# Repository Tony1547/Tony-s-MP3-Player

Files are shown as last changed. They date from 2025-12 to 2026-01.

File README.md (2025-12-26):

# Tony-s-MP3-Player
A custom MP3 player designed to bypass my school's ban on all cellular devices, which also bans over half the internet. How am I supposed to listen to my TF2 soundtrack? This project is also a good first step before I have to make my robot arm's PCB.

Onshape Link: https://cad.onshape.com/documents/4ae9d4a6ef44a3dbc4a2c6f3/w/3289807ef25710fc241d0646/e/3b21fd57c49c14028b7a0996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 

Google Sheets if needed: https://docs.google.com/spreadsheets/d/1tBs17rBeQA4046zbtyh8lai0--RzHnu4pUclCCczuA0/edit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

This is my first non-tutorial followed PCB! The following are pictures of the MP3 in Onshape and Kicad









|  1 | C2962032  | HYCW19-TF09-205B | HOAUC | SMD | | Micro SD card (TF card) Connector and Ejector Push-Push Surface Mount | yes | 5 | 5 | 5 |  0.3308 |  1.65 | 1.65 |
|---:|---|---|---|---|---|---|-----|----:|----:|----:|---:|---:|---:|
|  2 | C105578 | RC0603FR-071ML | YAGEO | 603 | | 100mW 1MΩ 75V ±100ppm/℃ Thick Film Resistor ±1% 0603 Chip Resistor - Surface Mount RoHS | yes | 100 | 100 | 100 |  0.0012 |  0.12 | 1.77 |
|  3 | C14675 | RC0603FR-07100KL | YAGEO | 603 | | 100mW 100kΩ 75V ±100ppm/℃ Thick Film Resistor ±1% 0603 Chip Resistor - Surface Mount RoHS | yes | 100 | 100 | 100 | 0.001 | 0.1 | 1.87 |
|  4 | C22843 | 0603WAF1501T5E | UNI-ROYAL | 603 | | 1.5kΩ ±1% 100mW 0603 Thick Film Resistor | yes | 100 | 100 | 100 |  0.0011 |  0.11 | 1.98 |
|  5 | C870490 | RT1206BRD071K13L | YAGEO | 1206 | | 250mW 1.13kΩ 200V ±25ppm/℃ Thin Film Resistor ±0.1% 1206 Chip Resistor - Surface Mount RoHS | yes |  10 |  10 |  10 |  0.0693 |  0.69 | 2.67 |
|  6 | C2906979  | FRC0603F1801TS | FOJAN | 603 | | 1.8kΩ ±1% 100mW 0603 Thick Film Resistor | yes | 100 | 100 | 100 | 0.001 | 0.1 | 2.77 |
|  7 | C2907044  | FRC0603F5101TS | FOJAN | 603 | | 5.1kΩ ±1% 100mW 0603 Thick Film Resistor | yes | 100 | 100 | 100 |  0.0009 |  0.09 | 2.86 |
|  8 | C782233 | RN73H1JTTD4642B25 | KOA | 603 | | 100mW 46.4kΩ ±25ppm/℃ Metal Film Resistor ±0.1% 0603 Chip Resistor - Surface Mount RoHS | yes | 1 | 1 | 1 |  0.2313 |  0.23 | 3.09 |
|  9 | C1705 | CL10A475KP8NNNC | Samsung Electro-Mechanics | 603 | | 4.7uF ±10% 10V Ceramic Capacitor X5R 0603 | yes |  50 |  50 |  50 |  0.0051 |  0.26 | 3.35 |
| 10 | C1653 | CL10C220JB8NNNC | Samsung Electro-Mechanics | 603 | | 22pF ±5% 50V Ceramic Capacitor C0G 0603 | yes | 100 | 100 | 100 |  0.0038 |  0.38 | 3.73 |
| 11 | C96346 | RC0805FR-07100KL | YAGEO | 805 | | 125mW 100kΩ 150V ±100ppm/℃ Thick Film Resistor ±1% 0805 Chip Resistor - Surface Mount RoHS  | yes | 100 | 100 | 100 |  0.0022 |  0.22 | 3.95 |
| 12 | C28323 | CL21B105KBFNNNE | Samsung Electro-Mechanics | 805 | | 1uF ±10% 50V Ceramic Capacitor X7R 0805 | yes |  20 |  20 |  20 |  0.0092 |  0.18 | 4.13 |
| 13 | C5189822  | CS2012X7R106M100NRE | SAMWHA | 805 | | 10uF ±20% 10V Ceramic Capacitor X7R 0805 | yes |  50 |  50 |  50 |  0.0074 |  0.37 | 4.5 |
| 14 | C170101 | CL31B225KCHSNNE | Samsung Electro-Mechanics | 1206 | | 2.2uF ±10% 100V Ceramic Capacitor X7R 1206 | yes | 5 | 5 | 5 |  0.0758 |  0.38 | 4.88 |
| 15 | C22548 | RC0603FR-071KL | YAGEO | 603 | | 100mW 1kΩ 75V ±100ppm/℃ Thick Film Resistor ±1% 0603 Chip Resistor - Surface Mount RoHS | yes | 100 | 100 | 100 |  0.0011 |  0.11 | 4.99 |
| 16 | C15850 | CL21A106KAYNNNE | Samsung Electro-Mechanics | 805 | | 10uF ±10% 25V Ceramic Capacitor X5R 0805 | yes |  20 |  20 |  20 |  0.0102 | 0.2 | 5.19 |
| 17 | C98220 | RC0603FR-0710KL | YAGEO | 603 | | 100mW 10kΩ 75V ±100ppm/℃ Thick Film Resistor ±1% 0603 Chip Resistor - Surface Mount RoHS | yes | 100 | 100 | 100 |  0.0011 |  0.11 | 5.3 |
| 18 | C1591 | CL10B104KB8NNNC | Samsung Electro-Mechanics | 603 | | 100nF ±10% 50V Ceramic Capacitor X7R 0603 | yes | 100 | 100 | 100 |  0.0026 |  0.26 | 5.56 |
| 19 | C19171390 | YLED0603R | YONGYUTAI | 603 | | Red LED Indication - Discrete 1.8V~2.4V 0603 | yes | 100 | 100 | 100 |  0.0055 |  0.55 | 6.11 |
| 20 | C157929 | S3B-PH-K-S(LF)(SN) | JST | Through Hole,Right Angle,P=2mm | | Connector Header 3 position 2mm Pitch 2A Right Angle -25℃~+85℃ | yes |  10 |  10 |  10 |  0.0433 |  0.43 | 6.54 |
| 21 | C2765186  | TYPE-C 16PIN 2MD(073) | SHOU HAN | SMD | | USB-C (USB TYPE-C) Receptacle Connector 16 Position Surface Mount, Right Angle | yes |  20 |  20 |  20 | 0.06 | 1.2 | 7.74 |
| 22 | C4991872  | SJ-3523-SMT-TR | CUI | SMD | | 1A 12V | yes | 1 | 1 | 1 |  1.3366 |  1.34 | 9.08 |
| 23 | C19171394 | YLED0603B | YONGYUTAI | 603 | | Blue LED Indication - Discrete 2.6V~3.2V 0603 | yes | 100 | 100 | 100 | 0.004 | 0.4 | 9.48 |
| 24 | C1338432  | STM32F401VEH6 | ST | UFBGA-100 | | ARM Cortex-M4 84MHz 81 UFBGA-100 Microcontrollers RoHS | yes | 1 | 1 | 1 |  7.9079 |  7.91 |  17.39 |
| 25 | C5248081  | HS91L02W2C01 | HS | - | | 0.91 128x32 SSD1306 I2C LCD, OLED, Graphic RoHS | yes | 1 | 1 | 1 |  1.9851 |  1.99 |  19.38 |
| 26 | C69901 | TPA6132A2RTER | TI | WQFN-16-EP(3x3) | | 2-Channel Class AB WQFN-16-EP(3x3) Audio Amplifiers RoHS | yes | 1 | 1 | 1 |  1.2295 |  1.23 |  20.61 |
| 27 | C486306 | VS1063A-L | VLSI | LQFP-48(7x7) | | 48kHz LQFP-48(7x7) Audio Special Purpose RoHS | yes | 1 | 1 | 1 |  9.3147 |  9.31 |  29.92 |
| 28 | C15464 | BQ24075RGTR | TI | QFN-16-EP(3x3) | | 4.35V~6.4V Lithium Battery 1.5A QFN-16-EP(3x3) Battery Chargers ICs RoHS | yes | 1 | 1 | 1 |  0.8901 |  0.89 |  30.81 |
| 29 | C26537 | NCP1117ST33T3G | onsemi | SOT-223 | | Linear Voltage Regulator IC Positive Fixed 1 Output 1A SOT-223 | yes | 5 | 5 | 5 |  0.2344 |  1.17 |  31.98 |
| 30 | C720477 | TS-1088-AR02016 | XUNPU | SMD,4x3mm | | Tactile Switch SPST 160gf 2mm SMD (SMT) Tab 4mm x 3mm Surface Mount | yes |  10 |  10 |  10 |  0.0423 |  0.42 | 32.4 |
| 31 | C7294738  | SD2012M28820001 | huaxindianzi | HC-49S-SMD | | Crystal 12.288MHz ±20ppm 20pF 80Ω HC-49S-SMD | yes | 5 | 5 | 5 | 0.076 |  0.38 |  32.78 |
| 32 | | 3.7V 500mAh Rechargeable Lithium Li-ion Polymer Battery | | | | Battery | | 1 | 1 | 1 | $3.99 | $3.99 | $36.77 |
| 33 | | PCB | JLCPCB | | | Custom Printed Circuit Board | | 1 | 1 | 1 | 0.4 |  5.12 | $41.89 |
| 34 | | 3D Prints | | | | Case | | 1 | 1 | 1 | Depends | | |

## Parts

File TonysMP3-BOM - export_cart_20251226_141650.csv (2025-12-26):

Index | LCSC# | MPN | Manufacturer | Package | Customer # | Description | RoHS | Quantity | MOQ | Multiple | Unit Price($) | Extended Price($) | Running Total($) | Product Link
1 | C2962032 | HYCW19-TF09-205B | HOAUC | SMD |  | Micro SD card (TF card) Connector and Ejector Push-Push Surface Mount | yes | 5 | 5 | 5 | 0.3308 | 1.65 | 1.65 | https://www.lcsc.com/product-detail/C2962032.html
2 | C105578 | RC0603FR-071ML | YAGEO | 603 |  | 100mW 1MΩ 75V ±100ppm/℃ Thick Film Resistor ±1% 0603 Chip Resistor - Surface Mount RoHS | yes | 100 | 100 | 100 | 0.0012 | 0.12 | 1.77 | https://www.lcsc.com/product-detail/C105578.html
3 | C14675 | RC0603FR-07100KL | YAGEO | 603 |  | 100mW 100kΩ 75V ±100ppm/℃ Thick Film Resistor ±1% 0603 Chip Resistor - Surface Mount RoHS | yes | 100 | 100 | 100 | 0.001 | 0.1 | 1.87 | https://www.lcsc.com/product-detail/C14675.html
4 | C22843 | 0603WAF1501T5E | UNI-ROYAL | 603 |  | 1.5kΩ ±1% 100mW 0603 Thick Film Resistor | yes | 100 | 100 | 100 | 0.0011 | 0.11 | 1.98 | https://www.lcsc.com/product-detail/C22843.html
5 | C870490 | RT1206BRD071K13L | YAGEO | 1206 |  | 250mW 1.13kΩ 200V ±25ppm/℃ Thin Film Resistor ±0.1% 1206 Chip Resistor - Surface Mount RoHS | yes | 10 | 10 | 10 | 0.0693 | 0.69 | 2.67 | https://www.lcsc.com/product-detail/C870490.html
6 | C2906979 | FRC0603F1801TS | FOJAN | 603 |  | 1.8kΩ ±1% 100mW 0603 Thick Film Resistor | yes | 100 | 100 | 100 | 0.001 | 0.1 | 2.77 | https://www.lcsc.com/product-detail/C2906979.html
7 | C2907044 | FRC0603F5101TS | FOJAN | 603 |  | 5.1kΩ ±1% 100mW 0603 Thick Film Resistor | yes | 100 | 100 | 100 | 0.0009 | 0.09 | 2.86 | https://www.lcsc.com/product-detail/C2907044.html
8 | C782233 | RN73H1JTTD4642B25 | KOA | 603 |  | 100mW 46.4kΩ ±25ppm/℃ Metal Film Resistor ±0.1% 0603 Chip Resistor - Surface Mount RoHS | yes | 1 | 1 | 1 | 0.2313 | 0.23 | 3.09 | https://www.lcsc.com/product-detail/C782233.html
9 | C1705 | CL10A475KP8NNNC | Samsung Electro-Mechanics | 603 |  | 4.7uF ±10% 10V Ceramic Capacitor X5R 0603 | yes | 50 | 50 | 50 | 0.0051 | 0.26 | 3.35 | https://www.lcsc.com/product-detail/C1705.html
10 | C1653 | CL10C220JB8NNNC | Samsung Electro-Mechanics | 603 |  | 22pF ±5% 50V Ceramic Capacitor C0G 0603 | yes | 100 | 100 | 100 | 0.0038 | 0.38 | 3.73 | https://www.lcsc.com/product-detail/C1653.html
11 | C96346 | RC0805FR-07100KL | YAGEO | 805 |  | 125mW 100kΩ 150V ±100ppm/℃ Thick Film Resistor ±1% 0805 Chip Resistor - Surface Mount RoHS | yes | 100 | 100 | 100 | 0.0022 | 0.22 | 3.95 | https://www.lcsc.com/product-detail/C96346.html
12 | C28323 | CL21B105KBFNNNE | Samsung Electro-Mechanics | 805 |  | 1uF ±10% 50V Ceramic Capacitor X7R 0805 | yes | 20 | 20 | 20 | 0.0092 | 0.18 | 4.13 | https://www.lcsc.com/product-detail/C28323.html
13 | C5189822 | CS2012X7R106M100NRE | SAMWHA | 805 |  | 10uF ±20% 10V Ceramic Capacitor X7R 0805 | yes | 50 | 50 | 50 | 0.0074 | 0.37 | 4.5 | https://www.lcsc.com/product-detail/C5189822.html
14 | C170101 | CL31B225KCHSNNE | Samsung Electro-Mechanics | 1206 |  | 2.2uF ±10% 100V Ceramic Capacitor X7R 1206 | yes | 5 | 5 | 5 | 0.0758 | 0.38 | 4.88 | https://www.lcsc.com/product-detail/C170101.html
15 | C22548 | RC0603FR-071KL | YAGEO | 603 |  | 100mW 1kΩ 75V ±100ppm/℃ Thick Film Resistor ±1% 0603 Chip Resistor - Surface Mount RoHS | yes | 100 | 100 | 100 | 0.0011 | 0.11 | 4.99 | https://www.lcsc.com/product-detail/C22548.html
16 | C15850 | CL21A106KAYNNNE | Samsung Electro-Mechanics | 805 |  | 10uF ±10% 25V Ceramic Capacitor X5R 0805 | yes | 20 | 20 | 20 | 0.0102 | 0.2 | 5.19 | https://www.lcsc.com/product-detail/C15850.html
17 | C98220 | RC0603FR-0710KL | YAGEO | 603 |  | 100mW 10kΩ 75V ±100ppm/℃ Thick Film Resistor ±1% 0603 Chip Resistor - Surface Mount RoHS | yes | 100 | 100 | 100 | 0.0011 | 0.11 | 5.3 | https://www.lcsc.com/product-detail/C98220.html
18 | C1591 | CL10B104KB8NNNC | Samsung Electro-Mechanics | 603 |  | 100nF ±10% 50V Ceramic Capacitor X7R 0603 | yes | 100 | 100 | 100 | 0.0026 | 0.26 | 5.56 | https://www.lcsc.com/product-detail/C1591.html
19 | C19171390 | YLED0603R | YONGYUTAI | 603 |  | Red LED Indication - Discrete 1.8V~2.4V 0603 | yes | 100 | 100 | 100 | 0.0055 | 0.55 | 6.11 | https://www.lcsc.com/product-detail/C19171390.html
20 | C157929 | S3B-PH-K-S(LF)(SN) | JST | Through Hole,Right Angle,P=2mm |  | Connector Header 3 position 2mm Pitch 2A Right Angle -25℃~+85℃ | yes | 10 | 10 | 10 | 0.0433 | 0.43 | 6.54 | https://www.lcsc.com/product-detail/C157929.html
21 | C2765186 | TYPE-C 16PIN 2MD(073) | SHOU HAN | SMD |  | USB-C (USB TYPE-C) Receptacle Connector 16 Position Surface Mount, Right Angle | yes | 20 | 20 | 20 | 0.06 | 1.2 | 7.74 | https://www.lcsc.com/product-detail/C2765186.html
22 | C4991872 | SJ-3523-SMT-TR | CUI | SMD |  | 1A 12V | yes | 1 | 1 | 1 | 1.3366 | 1.34 | 9.08 | https://www.lcsc.com/product-detail/C4991872.html
23 | C19171394 | YLED0603B | YONGYUTAI | 603 |  | Blue LED Indication - Discrete 2.6V~3.2V 0603 | yes | 100 | 100 | 100 | 0.004 | 0.4 | 9.48 | https://www.lcsc.com/product-detail/C19171394.html
24 | C1338432 | STM32F401VEH6 | ST | UFBGA-100 |  | ARM Cortex-M4 84MHz 81 UFBGA-100 Microcontrollers RoHS | yes | 1 | 1 | 1 | 7.9079 | 7.91 | 17.39 | https://www.lcsc.com/product-detail/C1338432.html
25 | C5248081 | HS91L02W2C01 | HS | - |  | 0.91 128x32 SSD1306 I2C LCD, OLED, Graphic RoHS | yes | 1 | 1 | 1 | 1.9851 | 1.99 | 19.38 | https://www.lcsc.com/product-detail/C5248081.html
26 | C69901 | TPA6132A2RTER | TI | WQFN-16-EP(3x3) |  | 2-Channel Class AB WQFN-16-EP(3x3) Audio Amplifiers RoHS | yes | 1 | 1 | 1 | 1.2295 | 1.23 | 20.61 | https://www.lcsc.com/product-detail/C69901.html
27 | C486306 | VS1063A-L | VLSI | LQFP-48(7x7) |  | 48kHz LQFP-48(7x7) Audio Special Purpose RoHS | yes | 1 | 1 | 1 | 9.3147 | 9.31 | 29.92 | https://www.lcsc.com/product-detail/C486306.html
28 | C15464 | BQ24075RGTR | TI | QFN-16-EP(3x3) |  | 4.35V~6.4V Lithium Battery 1.5A QFN-16-EP(3x3) Battery Chargers ICs RoHS | yes | 1 | 1 | 1 | 0.8901 | 0.89 | 30.81 | https://www.lcsc.com/product-detail/C15464.html
29 | C26537 | NCP1117ST33T3G | onsemi | SOT-223 |  | Linear Voltage Regulator IC Positive Fixed 1 Output 1A SOT-223 | yes | 5 | 5 | 5 | 0.2344 | 1.17 | 31.98 | https://www.lcsc.com/product-detail/C26537.html
30 | C720477 | TS-1088-AR02016 | XUNPU | SMD,4x3mm |  | Tactile Switch SPST 160gf 2mm SMD (SMT) Tab 4mm x 3mm Surface Mount | yes | 10 | 10 | 10 | 0.0423 | 0.42 | 32.4 | https://www.lcsc.com/product-detail/C720477.html
31 | C7294738 | SD2012M28820001 | huaxindianzi | HC-49S-SMD |  | Crystal 12.288MHz ±20ppm 20pF 80Ω HC-49S-SMD | yes | 5 | 5 | 5 | 0.076 | 0.38 | 32.78 | https://www.lcsc.com/product-detail/C7294738.html
32 |  | 3.7V 500mAh Rechargeable Lithium Li-ion Polymer Battery |  |  |  | Battery |  | 1 | 1 | 1 | $3.99 | $3.99 | $36.77 | https://www.aliexpress.us/w/wholesale-3.7v-li%2525252dion-500mah-Battery.html
33 |  | PCB | JLCPCB |  |  | Custom Printed Circuit Board |  | 1 | 1 | 1 | 0.4 | 5.12 | $41.89 | https://github.com/Tony1547/Tony-s-MP3-Player
34 |  | 3D Prints |  |  |  | Case |  | 1 | 1 | 1 | Depends |  |  | https://cad.onshape.com/documents/4ae9d4a6ef44a3dbc4a2c6f3/w/3289807ef25710fc241d0646/e/3b21fd57c49c14028b7a0996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

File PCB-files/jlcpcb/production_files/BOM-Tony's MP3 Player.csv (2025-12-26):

Comment | Designator | Footprint | LCSC | Quantity
Back | S4 | SW_TS-1088-AR02016 | C720477 | 1
Down | S7 | SW_TS-1088-AR02016 | C720477 | 1
HYCW19-TF09-205B | U4 | MICRO-SD-SMD_HYCW19-TF09-205B | C2962032 | 1
Left | S8 | SW_TS-1088-AR02016 | C720477 | 1
Power On/Off | S9 | SW_TS-1088-AR02016 | C720477 | 1
Right | S2 | SW_TS-1088-AR02016 | C720477 | 1
Select | S5 | SW_TS-1088-AR02016 | C720477 | 1
Up | S6 | SW_TS-1088-AR02016 | C720477 | 1
Vol+ | S1 | SW_TS-1088-AR02016 | C720477 | 1
Vol- | S3 | SW_TS-1088-AR02016 | C720477 | 1
10uf | C31 | C_0201_0603Metric_Pad0.64x0.40mm_HandSolder |  | 1
R | R10k1 | R_0201_0603Metric_Pad0.64x0.40mm_HandSolder |  | 1
4.7uf | C29 | C_0201_0603Metric_Pad0.64x0.40mm_HandSolder |  | 1
2.2uf | C33 | C_0201_0603Metric_Pad0.64x0.40mm_HandSolder |  | 1
1uf | C30 | C_0201_0603Metric_Pad0.64x0.40mm_HandSolder |  | 1
5.1k | R4 | R_0201_0603Metric_Pad0.64x0.40mm_HandSolder |  | 1
1k | R15 | R_0201_0603Metric_Pad0.64x0.40mm_HandSolder |  | 1
10k | R2 | R_0201_0603Metric_Pad0.64x0.40mm_HandSolder |  | 1
5.1k | R6 | R_0201_0603Metric_Pad0.64x0.40mm_HandSolder |  | 1
1.8k | R3 | R_0201_0603Metric_Pad0.64x0.40mm_HandSolder |  | 1
10k | R21 | R_0201_0603Metric_Pad0.64x0.40mm_HandSolder |  | 1
1uf | C20 | C_0201_0603Metric_Pad0.64x0.40mm_HandSolder |  | 1
Crystal | Y1 | Crystal_SMD_MicroCrystal_CC1V-T1A-2Pin_8.0x3.7mm_HandSoldering |  | 1
NCP1117-3.3_SOT223 | U6 | SOT-223-3_TabPin2 |  | 1
BQ24075RGT | U5 | VQFN-16-1EP_3x3mm_P0.5mm_EP1.6x1.6mm |  | 1
VLSI VS1063A-L | U3 | LQFP-48_L7.0-W7.0-P0.50-LS9.0-BL |  | 1
TI TPA6132A2RTER | U2 | WQFN-16_L3.0-W3.0-P0.50-TL-EP1.6 |  | 1
STM32F401VEH6 | U1 | UFBGA-100_L7.0-W7.0-P0.50-TL_ST_STM32 |  | 1
1.8k | R50 | R_0201_0603Metric_Pad0.64x0.40mm_HandSolder |  | 1
10k | R20 | R_0201_0603Metric_Pad0.64x0.40mm_HandSolder |  | 1
10k | R19 | R_0201_0603Metric_Pad0.64x0.40mm_HandSolder |  | 1
1k | R18 | R_0201_0603Metric_Pad0.64x0.40mm_HandSolder |  | 1
1k | R17 | R_0201_0603Metric_Pad0.64x0.40mm_HandSolder |  | 1
1k | R16 | R_0201_0603Metric_Pad0.64x0.40mm_HandSolder |  | 1
1k | R14 | R_0201_0603Metric_Pad0.64x0.40mm_HandSolder |  | 1
1k | R13 | R_0201_0603Metric_Pad0.64x0.40mm_HandSolder |  | 1
1k | R12 | R_0201_0603Metric_Pad0.64x0.40mm_HandSolder |  | 1
1k | R11 | R_0201_0603Metric_Pad0.64x0.40mm_HandSolder |  | 1
100k | R10 | R_0201_0603Metric_Pad0.64x0.40mm_HandSolder |  | 1
100k | R9 | R_0201_0603Metric_Pad0.64x0.40mm_HandSolder |  | 1
100k | R8 | R_0201_0603Metric_Pad0.64x0.40mm_HandSolder |  | 1
10k | R7 | R_0201_0603Metric_Pad0.64x0.40mm_HandSolder |  | 1
46.4k | R5 | R_0201_0603Metric_Pad0.64x0.40mm_HandSolder |  | 1
10k | R1 | R_0201_0603Metric_Pad0.64x0.40mm_HandSolder |  | 1
HS91L02W2C01 | OLED1 | OLED-TH_L38.0-W12.0_HS91L02W2C01 |  | 1
Conn_01x03 | J4 | JST_PH_S3B-PH-K_1x03_P2.00mm_Horizontal |  | 1
AudioJack | J2 | AUDIO-SMD_SJ-3524-SMT-TR-BE |  | 1
USB_C_Receptacle_USB2.0_16P | J1 | USB_C_Receptacle_Palconn_UTC16-G |  | 1
RED | D1 | LED_0201_0603Metric_Pad0.64x0.40mm_HandSolder |  | 1
100nf | C36 | C_0201_0603Metric_Pad0.64x0.40mm_HandSolder |  | 1
100n | C35 | C_0201_0603Metric_Pad0.64x0.40mm_HandSolder |  | 1
2.2uf | C34 | C_0201_0603Metric_Pad0.64x0.40mm_HandSolder |  | 1
10uf | C32 | C_0201_0603Metric_Pad0.64x0.40mm_HandSolder |  | 1
4.7uf | C28 | C_0201_0603Metric_Pad0.64x0.40mm_HandSolder |  | 1
1uf | C27 | C_0201_0603Metric_Pad0.64x0.40mm_HandSolder |  | 1
100nf | C23 | C_0201_0603Metric_Pad0.64x0.40mm_HandSolder |  | 1
22pf | C22 | C_0201_0603Metric_Pad0.64x0.40mm_HandSolder |  | 1
22pf | C21 | C_0201_0603Metric_Pad0.64x0.40mm_HandSolder |  | 1
100nf | C19 | C_0201_0603Metric_Pad0.64x0.40mm_HandSolder |  | 1
100nf | C18 | C_0201_0603Metric_Pad0.64x0.40mm_HandSolder |  | 1
100nf | C17 | C_0201_0603Metric_Pad0.64x0.40mm_HandSolder |  | 1
10uf | C16 | CP_Axial_L10.0mm_D4.5mm_P15.00mm_Horizontal |  | 1
10uf | C15 | CP_Axial_L10.0mm_D4.5mm_P15.00mm_Horizontal |  | 1
100nf | C14 | C_0201_0603Metric_Pad0.64x0.40mm_HandSolder |  | 1
100nf | C13 | C_0201_0603Metric_Pad0.64x0.40mm_HandSolder |  | 1
100nf | C12 | C_0201_0603Metric_Pad0.64x0.40mm_HandSolder |  | 1
1uf | C11 | C_0201_0603Metric_Pad0.64x0.40mm_HandSolder |  | 1
2.2uf | C10 | C_0201_0603Metric_Pad0.64x0.40mm_HandSolder |  | 1
1uf | C9 | C_0201_0603Metric_Pad0.64x0.40mm_HandSolder |  | 1
100nf | C8 | C_0201_0603Metric_Pad0.64x0.40mm_HandSolder |  | 1
10uf | C7 | CP_Axial_L10.0mm_D4.5mm_P15.00mm_Horizontal |  | 1
1uf | C6 | C_0201_0603Metric_Pad0.64x0.40mm_HandSolder |  | 1
1uf | C5 | C_0201_0603Metric_Pad0.64x0.40mm_HandSolder |  | 1
1uf | C4 | C_0201_0603Metric_Pad0.64x0.40mm_HandSolder |  | 1
1uf | C3 | C_0201_0603Metric_Pad0.64x0.40mm_HandSolder |  | 1
1uf | C2 | C_0201_0603Metric_Pad0.64x0.40mm_HandSolder |  | 1
1uf | C1 | C_0201_0603Metric_Pad0.64x0.40mm_HandSolder |  | 1
LED | BLUE1 | LED_0201_0603Metric_Pad0.64x0.40mm_HandSolder |  | 1
R | 100K2 | R_0201_0603Metric_Pad0.64x0.40mm_HandSolder |  | 1
R | 100k1 | R_0201_0603Metric_Pad0.64x0.40mm_HandSolder |  | 1
R | 1M1 | R_0201_0603Metric_Pad0.64x0.40mm_HandSolder |  | 1
R | 1.18k1 | R_0201_0603Metric_Pad0.64x0.40mm_HandSolder |  | 1
R | 1.13k1 | R_0201_0603Metric_Pad0.64x0.40mm_HandSolder |  | 1
R | 1.5k2 | R_0201_0603Metric_Pad0.64x0.40mm_HandSolder |  | 1
R | 1.5k1 | R_0201_0603Metric_Pad0.64x0.40mm_HandSolder |  | 1

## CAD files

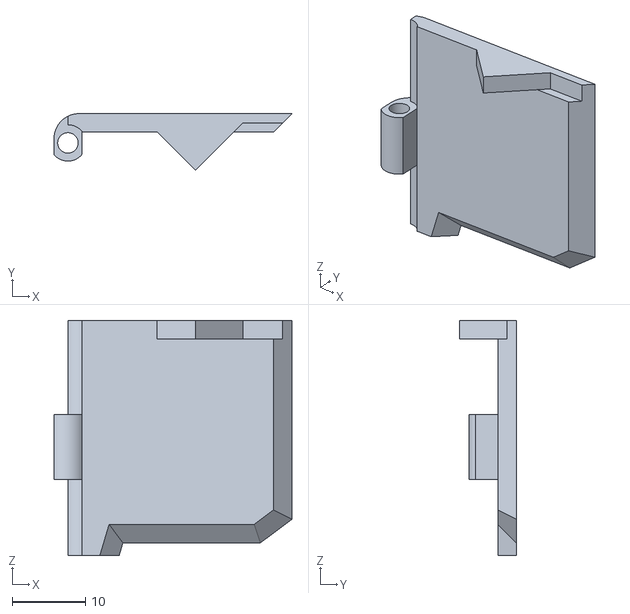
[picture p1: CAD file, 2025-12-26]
Case/Case - Part 3.stl
32.5 x 7.77 x 32.2

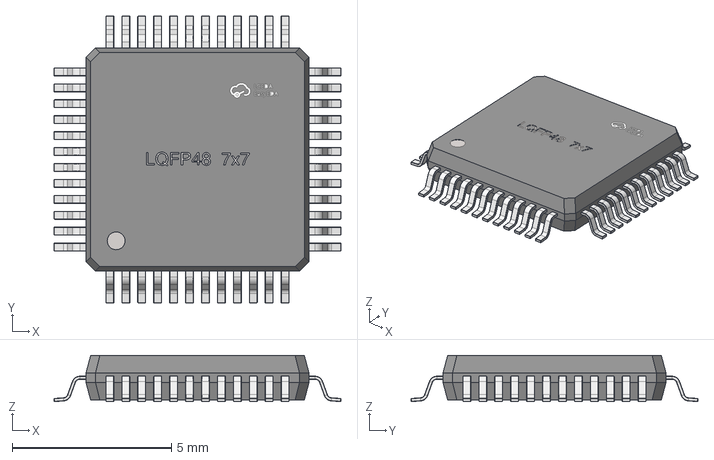
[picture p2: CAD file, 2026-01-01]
PCB-files/EASYEDA_MODELS/LQFP-48_L7.0-W7.0-H1.4-LS9.0-P0.50.step
9.01 x 9.01 x 1.45 mm

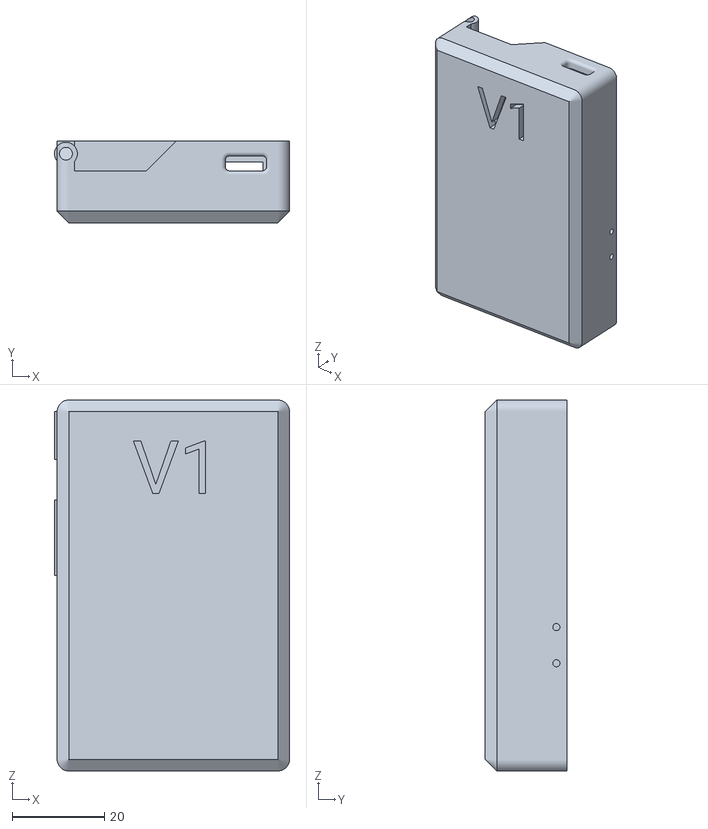
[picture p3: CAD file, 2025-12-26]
Case/Case - Part 1.stl
51.1 x 17.8 x 80.6

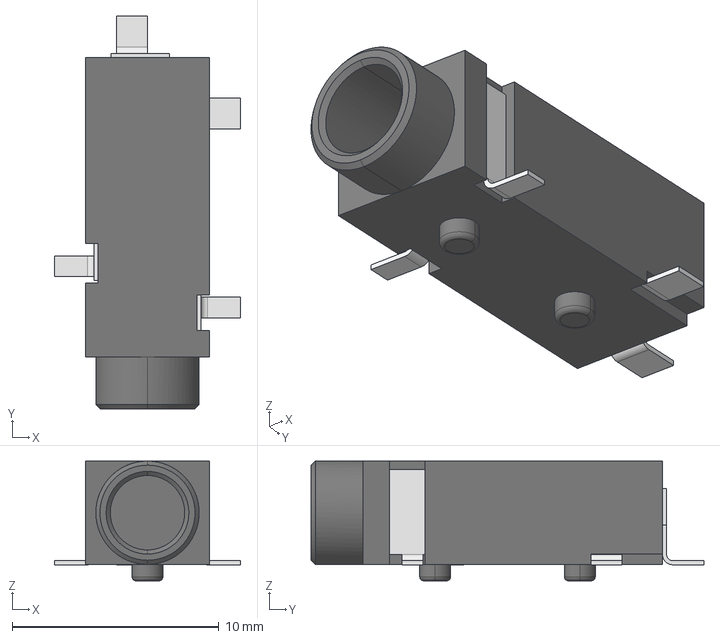
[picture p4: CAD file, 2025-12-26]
PCB-files/EASYEDA_MODELS/AUDIO-SMD_SJ-3524-SMT-TR-BE.step
9.00 x 19.0 x 5.80 mm

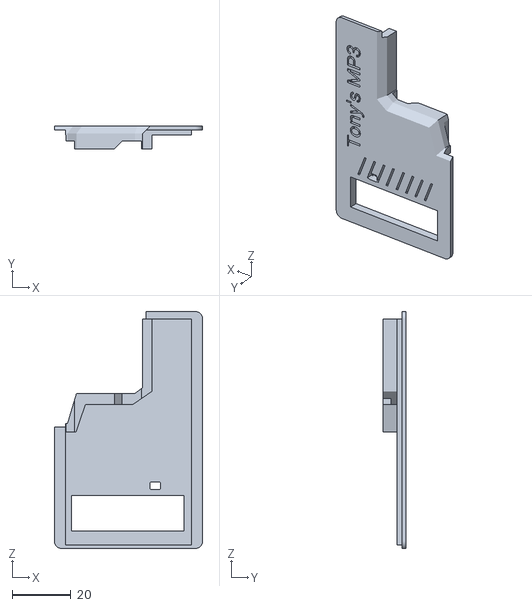
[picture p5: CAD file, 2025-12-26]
Case/Case - Part 2.stl
50.5 x 7.77 x 80.6

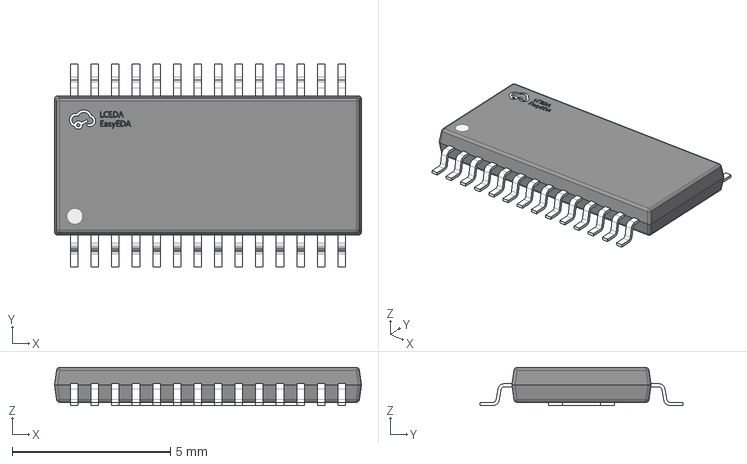
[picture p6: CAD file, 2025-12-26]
PCB-files/EASYEDA_MODELS/TSSOP-28_L9.7-W4.4-P0.65-LS6.4-BL-EP6.2.step
9.70 x 6.40 x 1.20 mm

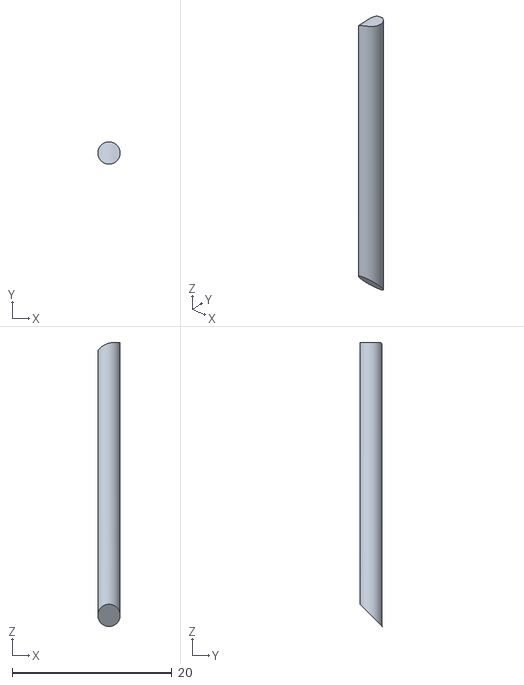
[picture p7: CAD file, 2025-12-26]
Case/Case - Part 4.stl
2.79 x 2.79 x 35.6

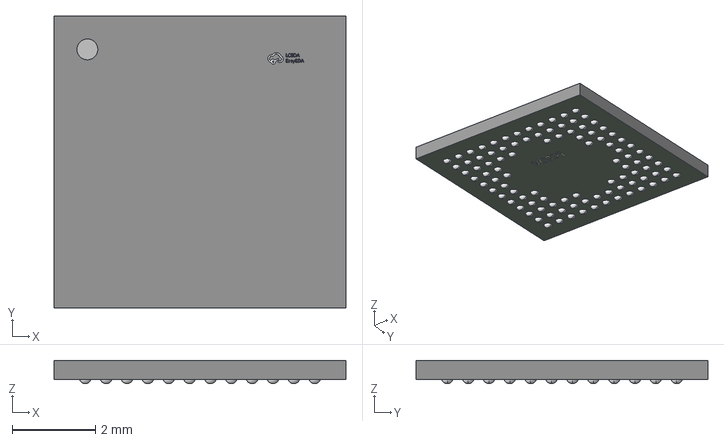
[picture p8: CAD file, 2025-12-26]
PCB-files/EASYEDA_MODELS/UFBGA-100_L7.0-W7.0-H0.6-P0.50-TL_STM32L072VBI6.step
7.00 x 7.00 x 0.56 mm

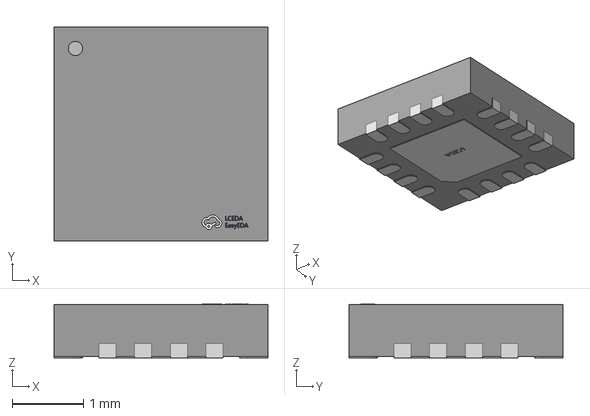
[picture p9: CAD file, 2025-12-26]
PCB-files/EASYEDA_MODELS/WQFN-16_L3.0-W3.0-P0.50-TL-EP1.6.step
3.00 x 3.00 x 0.751 mm

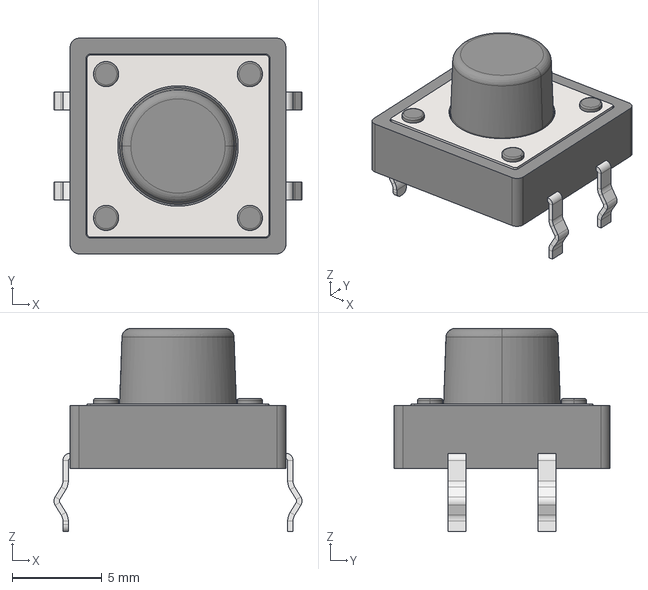
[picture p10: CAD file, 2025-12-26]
PCB-files/EASYEDA_MODELS/SW-TH_4P-L12.0-W12.0-P5.00-LS12.5.step
13.8 x 12.0 x 11.3 mm

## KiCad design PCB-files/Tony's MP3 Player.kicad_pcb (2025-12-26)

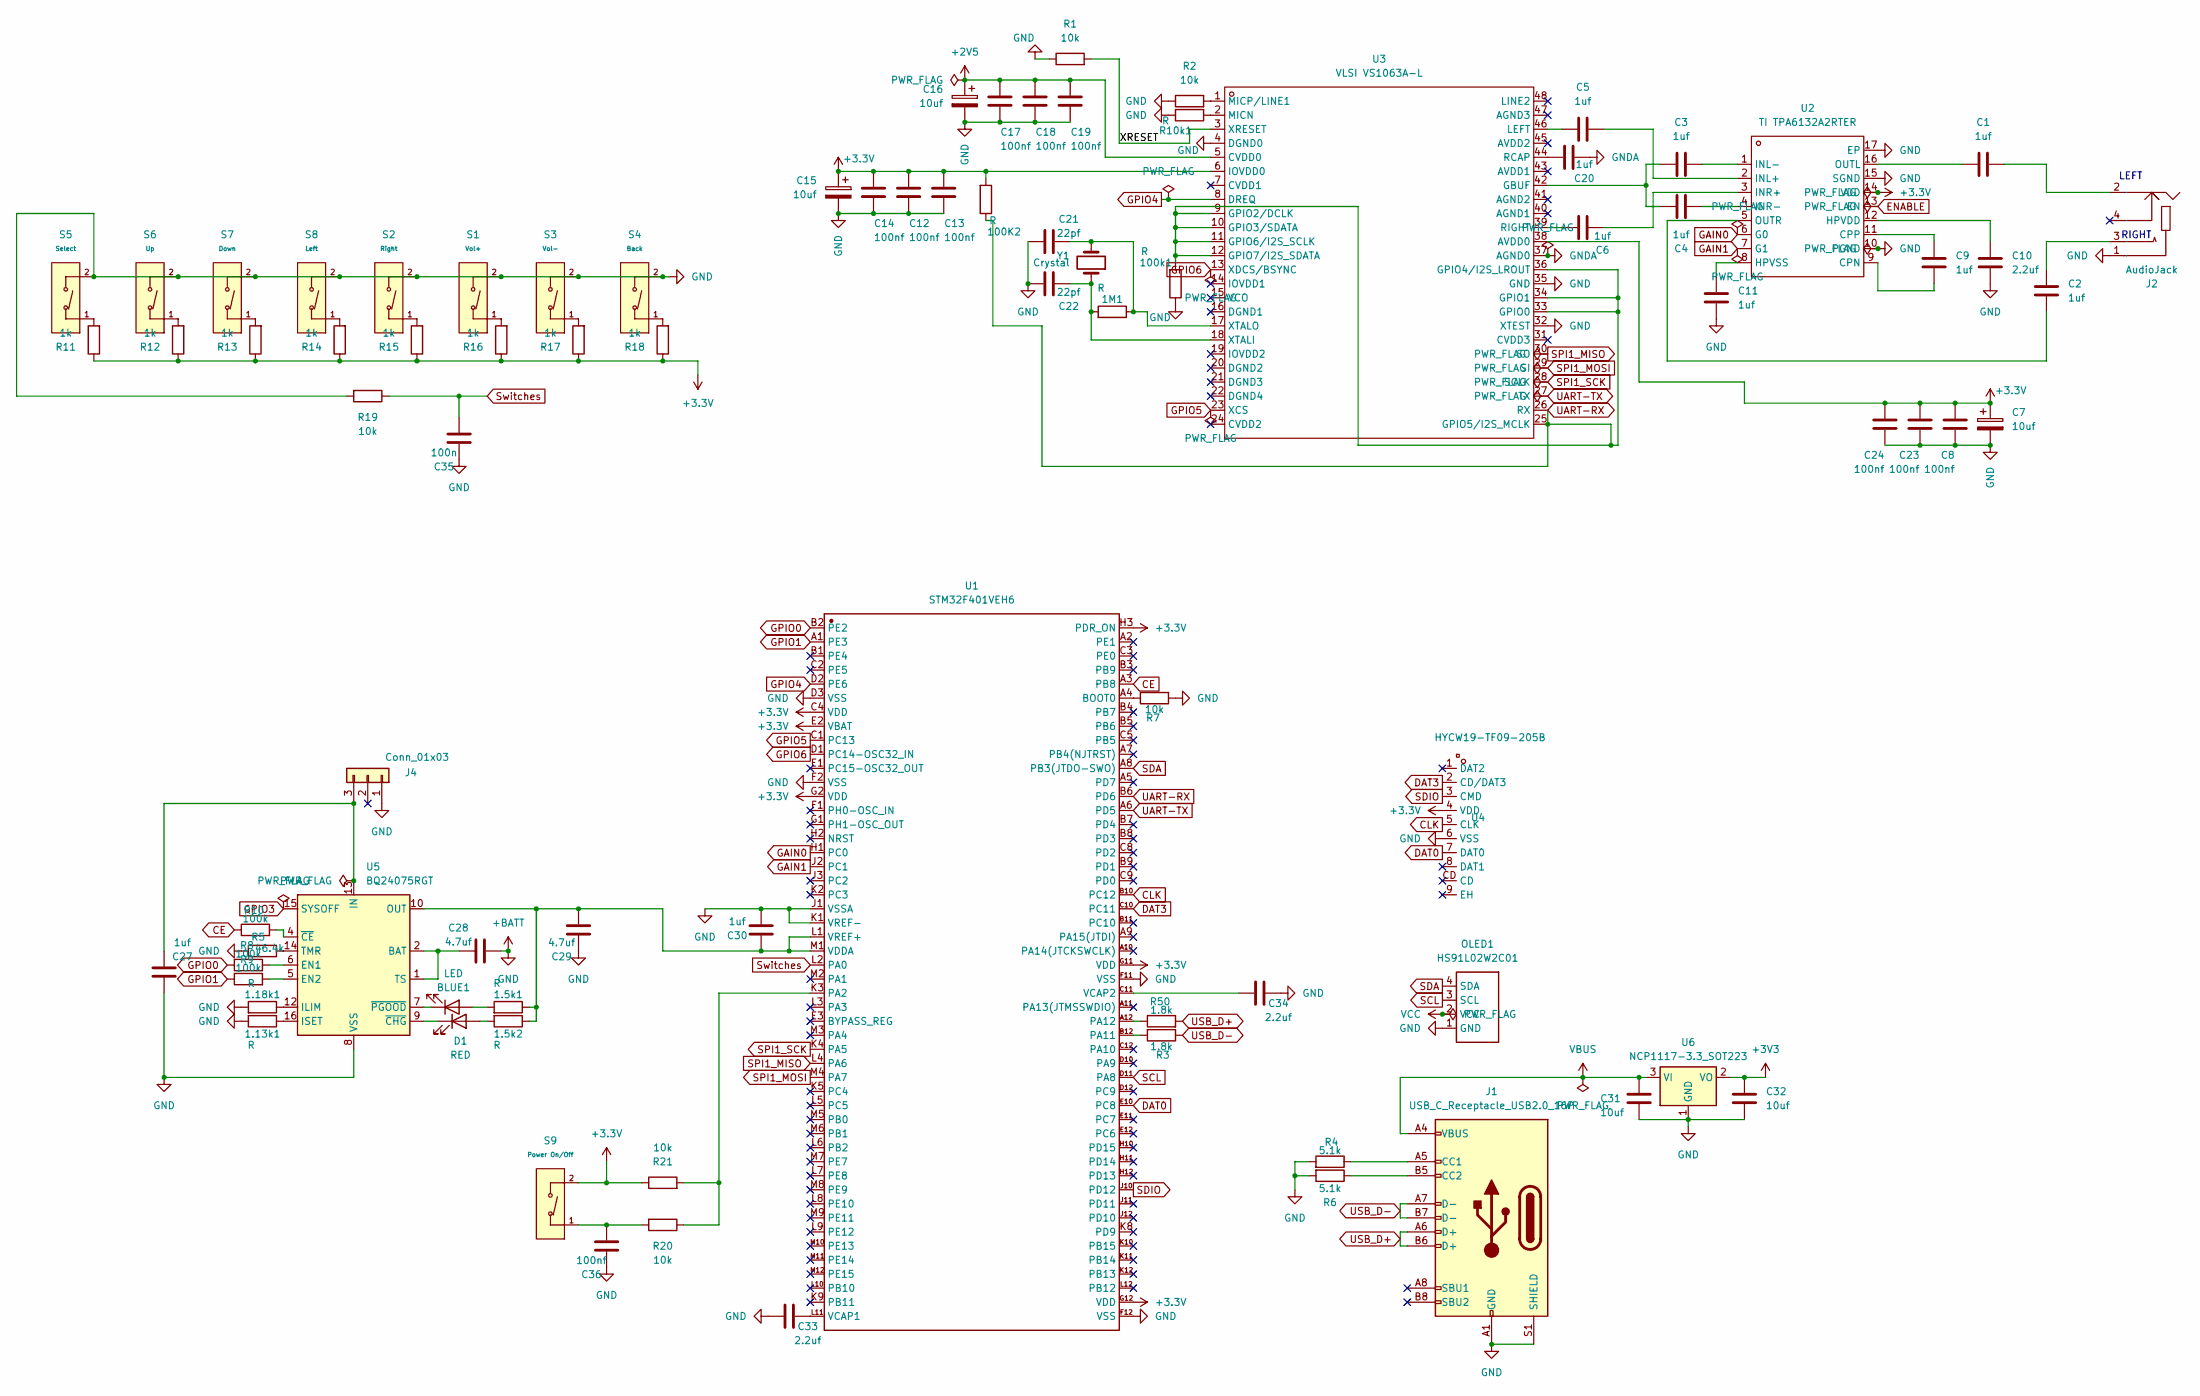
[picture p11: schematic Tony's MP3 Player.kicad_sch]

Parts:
1.5k1, 1.5k2, 1.13k1, 1.18k1, 1M1, 100K2, 100k1: R; R_0201_0603Metric_Pad0.64x0.40mm_HandSolder
BLUE1: LED; LED_0201_0603Metric_Pad0.64x0.40mm_HandSolder
C1, C2, C3, C4, C5, C6, C9, C11, C20, C27, C30: 1uf; C_0201_0603Metric_Pad0.64x0.40mm_HandSolder
C7, C15, C16: 10uf; CP_Axial_L10.0mm_D4.5mm_P15.00mm_Horizontal
C8, C12, C13, C14, C17, C18, C19, C23, C24, C36: 100nf; C_0201_0603Metric_Pad0.64x0.40mm_HandSolder
C10, C33, C34: 2.2uf; C_0201_0603Metric_Pad0.64x0.40mm_HandSolder
C21, C22: 22pf; C_0201_0603Metric_Pad0.64x0.40mm_HandSolder
C28, C29: 4.7uf; C_0201_0603Metric_Pad0.64x0.40mm_HandSolder
C31, C32: 10uf; C_0201_0603Metric_Pad0.64x0.40mm_HandSolder
C35: 100n; C_0201_0603Metric_Pad0.64x0.40mm_HandSolder
D1: RED; LED_0201_0603Metric_Pad0.64x0.40mm_HandSolder
J1: USB_C_Receptacle_USB2.0_16P; USB_C_Receptacle_Palconn_UTC16-G
J2: AudioJack; AUDIO-SMD_SJ-3524-SMT-TR-BE; Manufacturer Part SJ-3523-SMT-TR; LCSC Part Name SJ-3523-SMT-TR
J4: Conn_01x03; JST_PH_S3B-PH-K_1x03_P2.00mm_Horizontal
OLED1: HS91L02W2C01; OLED-TH_L38.0-W12.0_HS91L02W2C01; Manufacturer Part HS91L02W2C01
R1, R2, R7, R19, R20, R21: 10k; R_0201_0603Metric_Pad0.64x0.40mm_HandSolder
R3, R50: 1.8k; R_0201_0603Metric_Pad0.64x0.40mm_HandSolder
R4, R6: 5.1k; R_0201_0603Metric_Pad0.64x0.40mm_HandSolder
R5: 46.4k; R_0201_0603Metric_Pad0.64x0.40mm_HandSolder
R8, R9, R10: 100k; R_0201_0603Metric_Pad0.64x0.40mm_HandSolder
R10k1: R; R_0201_0603Metric_Pad0.64x0.40mm_HandSolder
R11, R12, R13, R14, R15, R16, R17, R18: 1k; R_0201_0603Metric_Pad0.64x0.40mm_HandSolder
S1: Vol+; SW_TS-1088-AR02016; Voltage Rating (Dc) 12V; Part TS-1088-AR02016; LCSC C720477
S2: Right; SW_TS-1088-AR02016; Voltage Rating (Dc) 12V; Part TS-1088-AR02016; LCSC C720477
S3: Vol-; SW_TS-1088-AR02016; Voltage Rating (Dc) 12V; Part TS-1088-AR02016; LCSC C720477
S4: Back; SW_TS-1088-AR02016; Voltage Rating (Dc) 12V; Part TS-1088-AR02016; LCSC C720477
S5: Select; SW_TS-1088-AR02016; Voltage Rating (Dc) 12V; Part TS-1088-AR02016; LCSC C720477
S6: Up; SW_TS-1088-AR02016; Voltage Rating (Dc) 12V; Part TS-1088-AR02016; LCSC C720477
S7: Down; SW_TS-1088-AR02016; Voltage Rating (Dc) 12V; Part TS-1088-AR02016; LCSC C720477
S8: Left; SW_TS-1088-AR02016; Voltage Rating (Dc) 12V; Part TS-1088-AR02016; LCSC C720477
S9: Power On/Off; SW_TS-1088-AR02016; Voltage Rating (Dc) 12V; Part TS-1088-AR02016; LCSC C720477
U1: STM32F401VEH6; UFBGA-100_L7.0-W7.0-P0.50-TL_ST_STM32; Manufacturer Part STM32F401VEH6
U2: TI TPA6132A2RTER; WQFN-16_L3.0-W3.0-P0.50-TL-EP1.6; Manufacturer Part TPA6132A2RTER; LCSC Part Name TPA6132A2RTER
U3: VLSI VS1063A-L; LQFP-48_L7.0-W7.0-P0.50-LS9.0-BL; Manufacturer Part VS1063A-L; LCSC Part Name VS1063A-L
U4: HYCW19-TF09-205B; MICRO-SD-SMD_HYCW19-TF09-205B; LCSC Part C2962032
U5: BQ24075RGT; VQFN-16-1EP_3x3mm_P0.5mm_EP1.6x1.6mm
U6: NCP1117-3.3_SOT223; SOT-223-3_TabPin2
Y1: Crystal; Crystal_SMD_MicroCrystal_CC1V-T1A-2Pin_8.0x3.7mm_HandSolder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

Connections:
+2V5: C16.1, C17.2, C18.2, C19.2, U3.5 (CVDD0)
+3.3V: 100K2.2, C7.1, C8.2, C12.2, C13.2, C14.2, C15.1, C23.2, C24.2, R11.1, R12.1, R13.1, R14.1, R15.1, R16.1, R17.1, R18.1, R21.1, S9.2 (B), U1.C4 (VDD), U1.E2 (VBAT), U1.G2 (VDD), U1.G11 (VDD), U1.G12 (VDD), U1.H3 (PDR_ON), U2.14 (VDD), U3.6 (IOVDD0), U3.38 (AVDD0), U4.4 (VDD)
+3V3: C32.1, U6.2 (VO)
+BATT: 1.13k1.2, 1.18k1.2, 100k1.1, C7.2, C8.1, C10.1, C11.1, C12.1, C13.1, C14.1, C15.2, C16.2, C17.1, C18.1, C19.1, C21.1, C22.1, C23.1, C24.1, C27.2, C28.2, C29.1, C30.1, C31.2, C32.2, C33.2, C34.1, C35.1, C36.1, J1.A1 (GND), J1.A12 (GND), J1.B1 (GND), J1.B12 (GND), J1.S1 (SHIELD), J2.1, J4.1, OLED1.1 (GND), R1.1, R2.1, R4.2, R5.2, R6.2, R7.2, R10k1.1, R19.2, S1.2 (B), S2.2 (B), S3.2 (B), S4.2 (B), S5.2 (B), S6.2 (B), S7.2 (B), S8.2 (B), U1.D3 (VSS), U1.F2 (VSS), U1.F11 (VSS), U1.F12 (VSS), U1.J1 (VSSA), U1.K1 (VREF-), U2.10 (PGND), U2.15 (SGND), U2.17 (EP), U3.4 (DGND0), U3.32 (XTEST), U3.35 (GND), U4.6 (VSS), U5.8 (VSS), U5.17 (VSS), U6.1 (GND)
/XRESET: R1.2, U3.3 (XRESET)
CE: R10.1, U1.A3 (PB8)
CLK: U1.B10 (PC12), U4.5 (CLK)
DAT0: U1.E10 (PC8), U4.7 (DAT0)
DAT3: U1.C10 (PC11), U4.2 (CD/DAT3)
ENABLE: U2.13 (EN)
GAIN0: U1.H1 (PC0), U2.6 (G0)
GAIN1: U1.J2 (PC1), U2.7 (G1)
GNDA: C20.1, U3.37 (AGND0)
GPIO0: R8.1, U1.B2 (PE2)
GPIO1: R9.1, U1.A1 (PE3)
GPIO3: U5.15 (SYSOFF)
GPIO4: U1.D2 (PE6), U3.8 (DREQ)
GPIO5: U1.C1 (PC13), U3.23 (XCS)
GPIO6: U1.D1 (PC14-OSC32_IN), U3.13 (XDCS/BSYNC)
unnamed: 1.5k1.2, BLUE1.2 (A)
unnamed: BLUE1.1 (K), U5.7 (~PGOOD)
unnamed: C1.2, J2.2
unnamed: C2.2, J2.3
unnamed: 1.5k2.2, D1.2 (A)
unnamed: D1.1 (K), U5.9 (~CHG)
unnamed: J1.A5 (CC1), R4.1
unnamed: J1.B5 (CC2), R6.1
unnamed: C27.1, J4.3, U5.13 (IN)
unnamed: R16.2, S1.1 (A)
unnamed: R15.2, S2.1 (A)
unnamed: R17.2, S3.1 (A)
unnamed: R18.2, S4.1 (A)
unnamed: R11.2, S5.1 (A)
unnamed: R12.2, S6.1 (A)
unnamed: R13.2, S7.1 (A)
unnamed: R14.2, S8.1 (A)
unnamed: C36.2, R20.2, S9.1 (A)
unnamed: R7.1, U1.A4 (BOOT0)
unnamed: R20.1, R21.2, U1.K3 (PA2)
unnamed: R3.2, U1.B12 (PA11)
unnamed: R50.1, U1.A12
unnamed: C33.1, U1.L11 (VCAP1)
unnamed: C34.2, U1.C11 (VCAP2)
unnamed: 1.5k1.1, 1.5k2.1, C29.2, C30.2, U1.L1 (VREF+), U1.M1 (VDDA), U5.10 (OUT), U5.11 (OUT)
unnamed: C9.1, U2.9 (CPN)
unnamed: C9.2, U2.11 (CPP)
unnamed: C10.2, U2.12 (HPVDD)
unnamed: C11.2, U2.8 (HPVSS)
unnamed: C5.2, U2.2 (INL+)
unnamed: C3.2, U2.1 (INL-)
unnamed: C6.2, U2.3 (INR+)
unnamed: C4.2, U2.4 (INR-)
unnamed: C1.1, U2.16 (OUTL)
unnamed: C2.1, U2.5 (OUTR)
unnamed: C3.1, C4.1, U3.42 (GBUF)
unnamed: C5.1, U3.46 (LEFT)
unnamed: R10k1.2, U3.2 (MICN)
unnamed: R2.2, U3.1 (MICP/LINE1)
unnamed: C20.2, U3.44 (RCAP)
unnamed: C6.1, U3.39 (RIGHT)
unnamed: 1M1.2, C22.2, U3.18 (XTALI), Y1.1
unnamed: 1M1.1, C21.2, U3.17 (XTALO), Y1.2
unnamed: R8.2, U5.6 (EN1)
unnamed: R9.2, U5.5 (EN2)
unnamed: 1.18k1.1, U5.12 (ILIM)
unnamed: 1.13k1.1, U5.16 (ISET)
unnamed: R5.1, U5.14 (TMR)
unnamed: C28.1, U5.1 (TS), U5.2 (BAT), U5.3 (BAT)
unnamed: R10.2, U5.4 (~CE)
SCL: OLED1.3 (SCL), U1.D11 (PA8)
SDA: OLED1.4 (SDA), U1.A8 (PB3(JTDO-SWO))
SDIO: U1.J10 (PD12), U4.3 (CMD)
SPI1_MISO: U1.L4 (PA6), U3.30 (SO)
SPI1_MOSI: U1.M4 (PA7), U3.29 (SI)
SPI1_SCK: U1.K4 (PA5), U3.28 (SCLK)
Switches: C35.2, R19.1, U1.L2 (PA0)
UART-RX: 100K2.1, 100k1.2, U1.B6 (PD6), U3.9 (GPIO2/DCLK), U3.10 (GPIO3/SDATA), U3.11 (GPIO6/I2S_SCLK), U3.12 (GPIO7/I2S_SDATA), U3.25 (GPIO5/I2S_MCLK), U3.26 (RX), U3.33 (GPIO0), U3.34 (GPIO1), U3.36 (GPIO4/I2S_LROUT)
UART-TX: U1.A6 (PD5), U3.27 (TX)
USB_D+: J1.A6 (D+), J1.B6 (D+), R50.2
USB_D-: J1.A7 (D-), J1.B7 (D-), R3.1
VBUS: C31.1, J1.A4 (VBUS), J1.A9 (VBUS), J1.B4 (VBUS), J1.B9 (VBUS), U6.3 (VI)
VCC: OLED1.2 (VCC)

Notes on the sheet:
RIGHT
LEFT

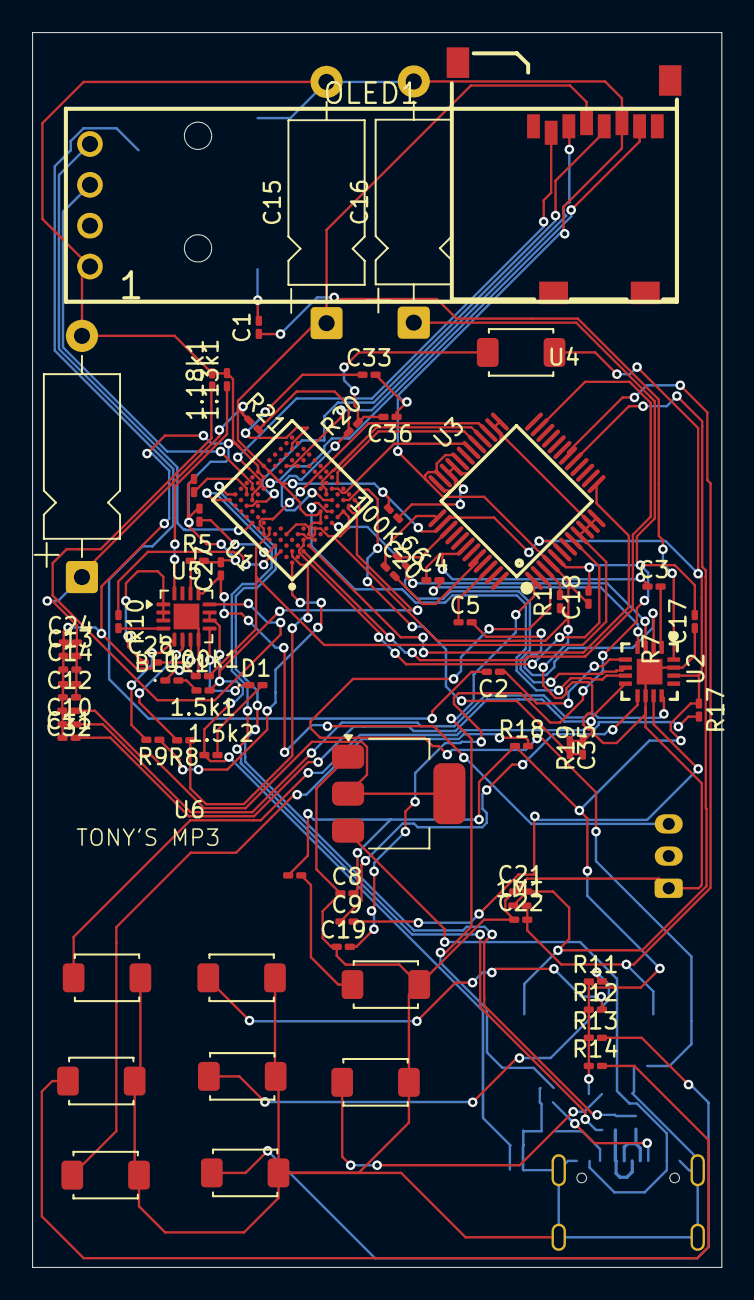
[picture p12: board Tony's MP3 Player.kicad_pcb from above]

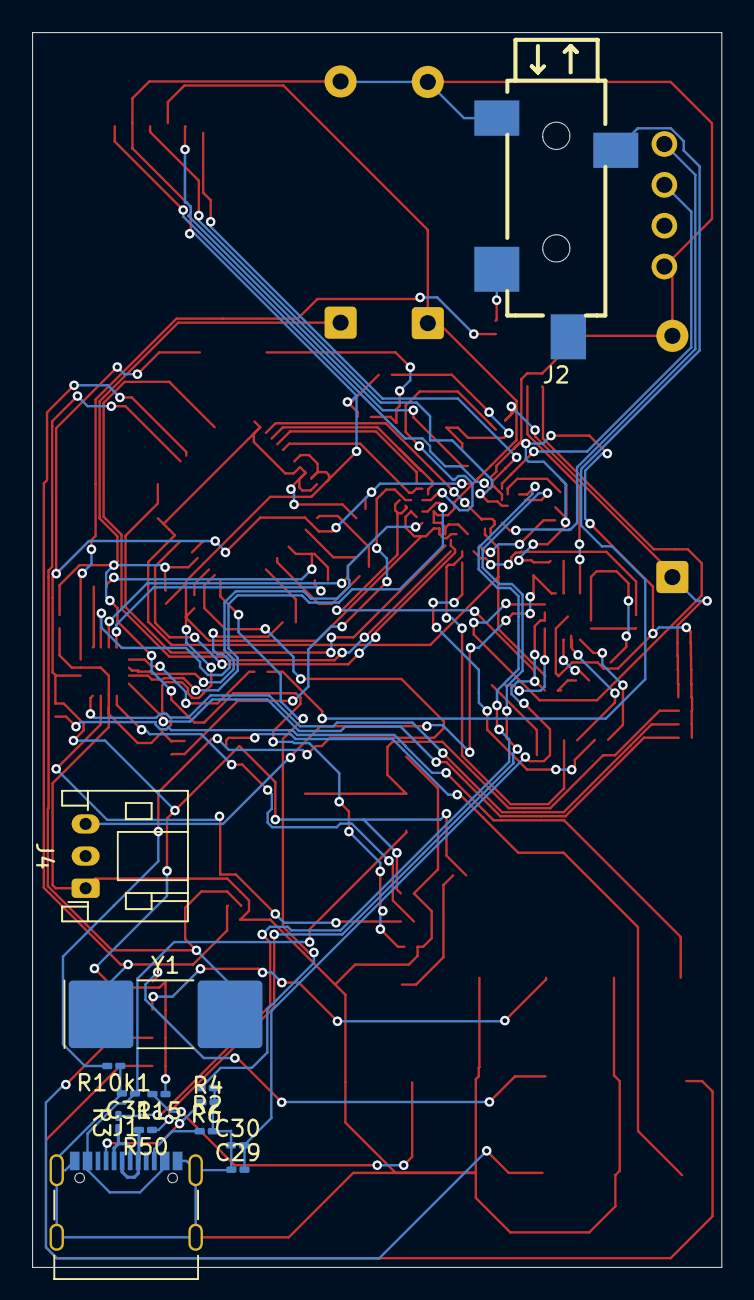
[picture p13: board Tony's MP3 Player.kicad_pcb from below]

Board: 2 copper layers, 42.9 x 76.8 mm, 86 parts (14 on the bottom side), 79 nets.

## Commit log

2025-12-26 copy files
    [AUDIO-SMD_SJ-3524-SMT-TR-BE.step, BOM-Tony's MP3 Player.csv, Case - Part 1.stl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]
2025-12-26 move gerb files
    [Tony's MP3 Player-B_Cu.gbr, Tony's MP3 Player-B_Mask.gbr, Tony's MP3 Player-B_Paste.gbr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]
